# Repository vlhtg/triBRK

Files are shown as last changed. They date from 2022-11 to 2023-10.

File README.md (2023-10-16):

# triBRK
<b>three Button Rhythm Keyboard</b> is a cheap and simple to produce input device for various rythm games, aiming to fill the niche of three button devices.

This is my first project both in KiCAD and in STM32Cube.

### Hardware

Built around a STM32 "blue-pill", it uses cheap commonly available parts and a 3D printed case. Unlike AVR-based alternatives this is even cheaper, as blue-pills are around 2-3 euros on Chinese websites. Initial designs had a STM32 chip and the auxilliary components placed directly on the board, but compared to just soldering a pre-made board this just resulted in useless complexity, longer building times and surprisingly, higher costs per unit.

### Images

<p float="left">
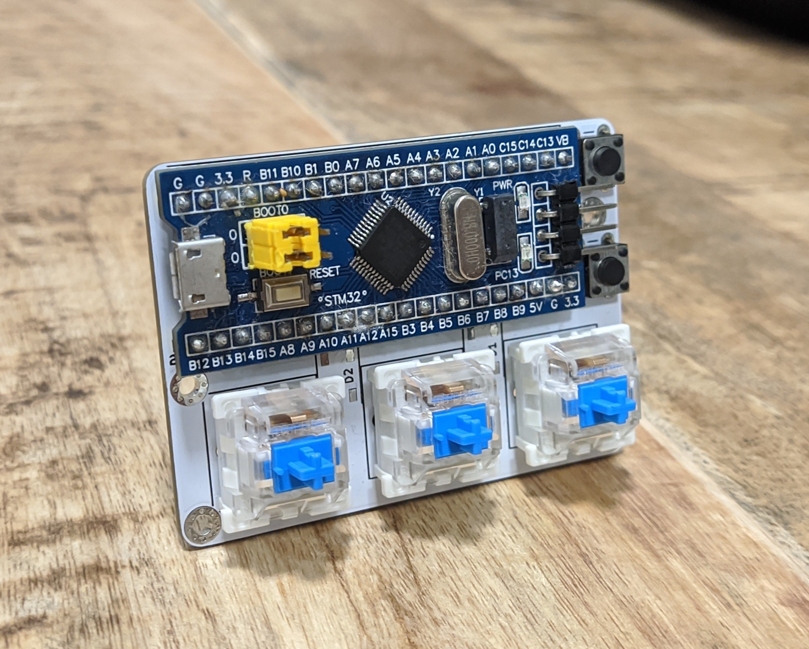
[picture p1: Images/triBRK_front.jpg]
Front
  
  &nbsp&nbsp&nbsp&nbsp&nbsp
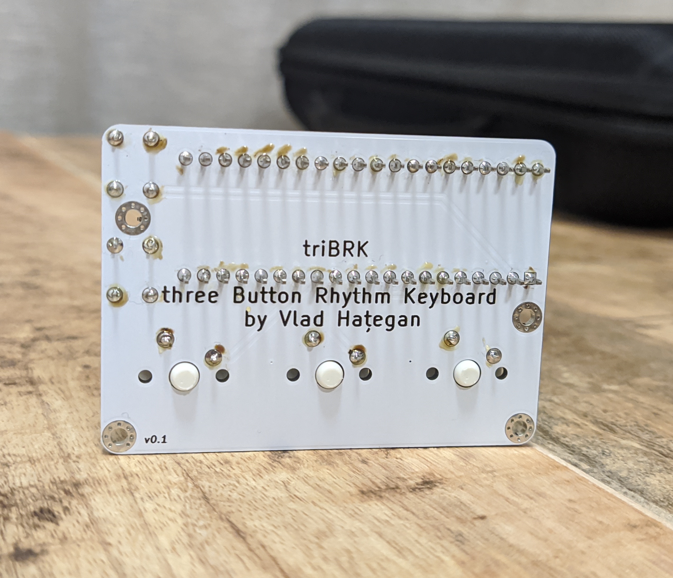
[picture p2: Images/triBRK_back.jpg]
Back
  
</p>

### To be done

Even though the project is functional, there are still a lot of things that are left to be done:

* Implement an easy to use key programming method using the additional microswitches.
* Implement RGB LED functionality.
* Create variant with hot-swappable switch connectors.
* ~~Make 3D printed case.~~ DONE!

### How to make one

#### What you need

* A blue-pill STM32F103C6T6A board.
* A ST-Link (I have used a clone) and jumpers.
* A program to flash the board, for Linux I have used [this](https://github.com/stlink-org/stlink).
* Three mechanical switches of your choice, compatible with the MX switch layout, prefferably of the 5 pin variety.
* Two standard THT microswitches/buttons.
* A PCB ordered by using the provided Gerber files.

#### How to assemble

* Order the PCB from a custom manufacturer and wait for it to arrive (I have used JLCPCB, any alternative is just as good).
* If blue-pil does not come with soldered jumpers, solder the jumpers.
* Solder the two small microswitches and the three switches to the board.
* Solder the blue-pill on the board.
* Connect the blue-pill to your PC via the ST-Link.
* Flash it with the .bin available in Releases.
* Enjoy your new device!

### Thanks to:

* This library for the blue-pill footprint: https://github.com/Mr-JoE1/Kicad-STM32_bluebill
* This library for MX switches footprint: https://github.com/perigoso/keyswitch-kicad-library
* STM for the USB HID libraries that are included with STM32CubeIDE.
* [This](https://www.instructables.com/STM32-As-HID-USB-Keyboard-STM32-Tutorials/) guide for helping me navigate the Configuration interface of the IDE for the first time and explaining how to modify the generated code from the default mouse behaviour to a keyboard one.

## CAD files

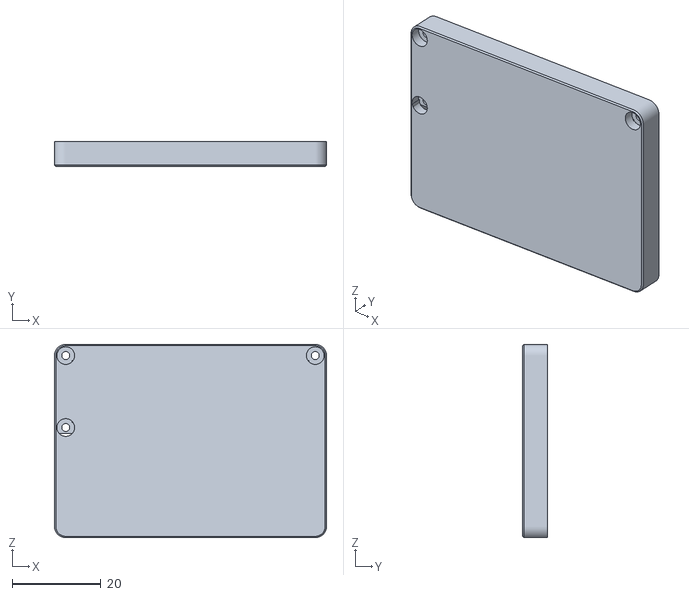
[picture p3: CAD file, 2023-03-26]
STLs/lower.stl
61.5 x 5.60 x 43.7

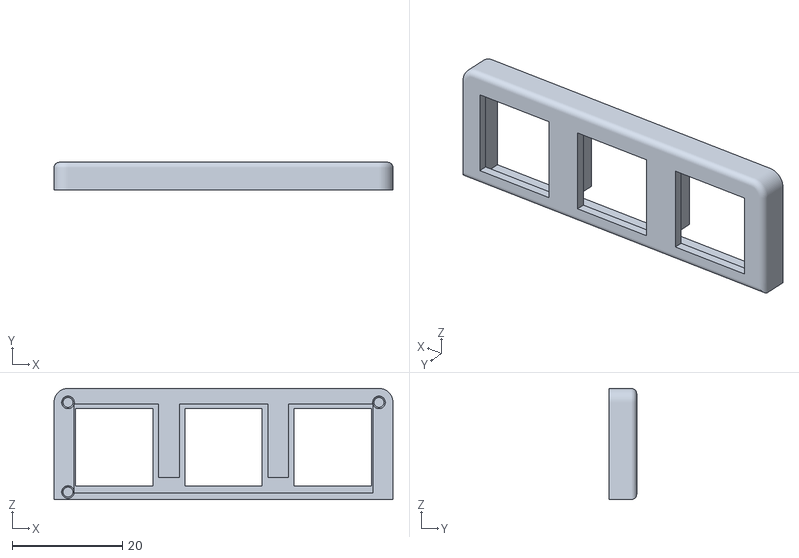
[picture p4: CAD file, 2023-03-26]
STLs/upper.stl
61.5 x 5.00 x 20.2

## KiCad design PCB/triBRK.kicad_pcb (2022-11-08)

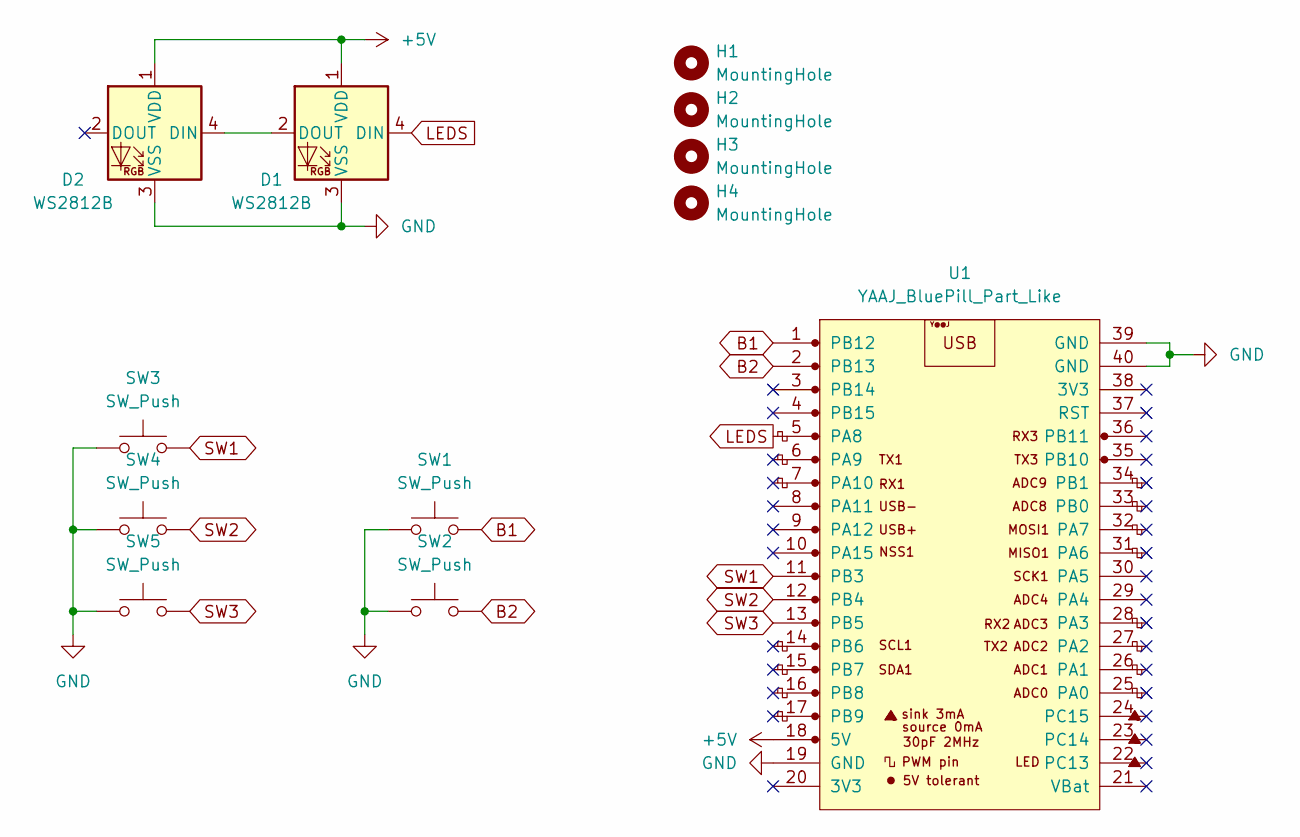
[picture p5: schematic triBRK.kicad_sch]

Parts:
D1, D2: WS2812B; LED_WS2812B_PLCC4_5.0x5.0mm_P3.2mm
H1, H2, H3, H4: MountingHole; MountingHole_2.2mm_M2_Pad_Via
SW1, SW2: SW_Push; SW_PUSH_6mm
SW3, SW4, SW5: SW_Push; SW_Cherry_MX_1.00u_PCB
U1: YAAJ_BluePill_Part_Like; YAAJ_BluePill_1

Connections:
+5V: D1.1 (VDD), D2.1 (VDD), U1.18 (5V)
B1: SW1.2, U1.1 (PB12)
B2: SW2.2, U1.2 (PB13)
GND: D1.3 (VSS), D2.3 (VSS), SW1.1, SW2.1, SW3.1, SW4.1, SW5.1, U1.19 (GND), U1.39 (GND), U1.40 (GND)
LEDS: D1.4 (DIN), U1.5 (PA8)
unnamed: D1.2 (DOUT), D2.4 (DIN)
SW1: SW3.2, U1.11 (PB3)
SW2: SW4.2, U1.12 (PB4)
SW3: SW5.2, U1.13 (PB5)

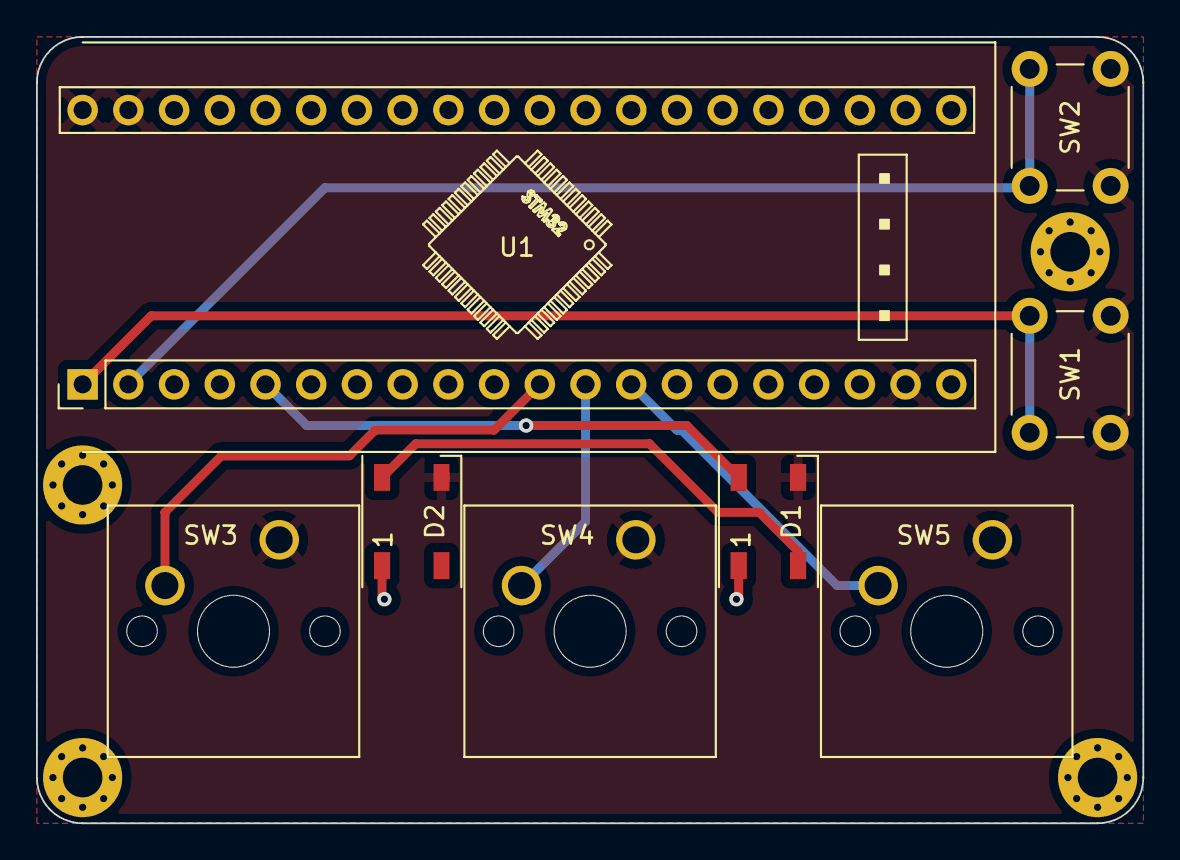
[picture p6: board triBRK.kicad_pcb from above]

Board: 2 copper layers, 61.5 x 43.7 mm, 12 parts (0 on the bottom side), 9 nets.

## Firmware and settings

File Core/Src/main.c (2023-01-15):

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
/* Includes ------------------------------------------------------------------*/
#include "main.h"
#include "usb_device.h"
#include "stdbool.h"


/* USER CODE BEGIN PV */
extern USBD_HandleTypeDef hUsbDeviceFS;

typedef struct
{
	uint8_t MODIFIER;
	uint8_t RESERVED;
	uint8_t KEYCODE1;
	uint8_t KEYCODE2;
	uint8_t KEYCODE3;
	uint8_t KEYCODE4;
	uint8_t KEYCODE5;
	uint8_t KEYCODE6;
}subKeyBoard;

subKeyBoard keyBoardHIDsub = {0,0,0,0,0,0,0,0};
/* USER CODE END PV */

void SystemClock_Config(void);
static void MX_GPIO_Init(void);
/**
  * @brief  The application entry point.
  * @retval int
  */
int main(void)
{
  /* MCU Configuration--------------------------------------------------------*/

  /* Reset of all peripherals, Initializes the Flash interface and the Systick. */
  HAL_Init();

  /* Configure the system clock */
  SystemClock_Config();

  /* Initialize all configured peripherals */
  MX_GPIO_Init();
  MX_USB_DEVICE_Init();
  /* Infinite loop */
  /* USER CODE BEGIN WHILE */
  while (1)
  {
    /* USER CODE END WHILE */

    /* USER CODE BEGIN 3 */

	  bool SW1status = !HAL_GPIO_ReadPin (GPIOB, GPIO_PIN_3);
	  bool SW2status = !HAL_GPIO_ReadPin (GPIOB, GPIO_PIN_4);
	  bool SW3status = !HAL_GPIO_ReadPin (GPIOB, GPIO_PIN_5);

	  bool B1status = !HAL_GPIO_ReadPin (GPIOB, GPIO_PIN_12);
	  bool B2status = !HAL_GPIO_ReadPin (GPIOB, GPIO_PIN_13);

	  if(SW1status) {
		  keyBoardHIDsub.MODIFIER=0x01;
	  } else {
		  keyBoardHIDsub.MODIFIER=0x00;
	  }

	  if(SW2status && SW3status) {
		  keyBoardHIDsub.KEYCODE1=0x06;
		  keyBoardHIDsub.KEYCODE2=0x19;
	  }
	  if(SW2status && !SW3status) {
	  		  keyBoardHIDsub.KEYCODE1=0x06;
	  		  keyBoardHIDsub.KEYCODE2=0x00;
	  }
	  if(!SW2status && !SW3status) {
	  		  keyBoardHIDsub.KEYCODE1=0x00;
	  		  keyBoardHIDsub.KEYCODE2=0x00;
	  }
	  if(!SW2status && SW3status) {
			  keyBoardHIDsub.KEYCODE1=0x19;
			  keyBoardHIDsub.KEYCODE2=0x00;
	  }

	  USBD_HID_SendReport(&hUsbDeviceFS, &keyBoardHIDsub,sizeof(keyBoardHIDsub));
	  HAL_Delay(10);

//	  keyBoardHIDsub.MODIFIER=0x02;  // To press shift key
//	  keyBoardHIDsub.KEYCODE1=0x04;  // Press A key
//	  keyBoardHIDsub.KEYCODE2=0x05;  // Press B key
//	  keyBoardHIDsub.KEYCODE3=0x06;  // Press C key
//	  USBD_HID_SendReport(&hUsbDeviceFS,&keyBoardHIDsub,sizeof(keyBoardHIDsub));
//	  HAL_Delay(50); 		       // Press all key for 50 milliseconds
//	  keyBoardHIDsub.MODIFIER=0x00;  // To release shift key
//	  keyBoardHIDsub.KEYCODE1=0x00;  // Release A key
//	  keyBoardHIDsub.KEYCODE2=0x00;  // Release B key
//	  keyBoardHIDsub.KEYCODE3=0x00;  // Release C key
//	  USBD_HID_SendReport(&hUsbDeviceFS,&keyBoardHIDsub,sizeof(keyBoardHIDsub));
//	  HAL_Delay(1000); 	       // Repeat this task on every 1 second
  }
  /* USER CODE END 3 */
}

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


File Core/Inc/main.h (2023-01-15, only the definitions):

#define B1_Pin GPIO_PIN_12
#define B1_GPIO_Port GPIOB
#define B2_Pin GPIO_PIN_13
#define B2_GPIO_Port GPIOB
#define SW1_Pin GPIO_PIN_3
#define SW1_GPIO_Port GPIOB
#define SW2_Pin GPIO_PIN_4
#define SW2_GPIO_Port GPIOB
#define SW3_Pin GPIO_PIN_5
#define SW3_GPIO_Port GPIOB

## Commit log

2022-10-20 Uploaded PCB files
    [triBRK.kicad_pcb, triBRK.kicad_sch]
2022-10-20 Small changes
    [triBRK.kicad_pcb, triBRK.kicad_sch]
2022-10-20 corrected typo
    [triBRK.kicad_pcb]
2022-10-20 Rounder corners + other optimisations
    [triBRK.kicad_pcb]
2022-11-08 Changed holes specs and optimized wiring, nicer schematic also
    [triBRK.kicad_pcb, triBRK.kicad_sch]
2022-11-08 Modified silkscreen
    [triBRK.kicad_pcb]
2023-01-15 Added STM32 code
    [triBRK Debug.cfg]
2023-01-15 Updated readme to reflect current state of project
2023-03-26 Added 3D models for the case
    [lower.stl, upper.stl]
2023-10-16 Updated readme with case info

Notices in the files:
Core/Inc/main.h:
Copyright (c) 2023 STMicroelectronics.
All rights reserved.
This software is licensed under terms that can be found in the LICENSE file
